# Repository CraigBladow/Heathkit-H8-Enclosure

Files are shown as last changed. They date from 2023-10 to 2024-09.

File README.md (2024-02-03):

# Heathkit-H8-Enclosure
A do it yourself enclosure designed for the Heathkit H8 Computer

Status: This is currently an incomplete work in progress.

Important: Review the license for this project before utilizing any of designs or information provided.

H8 Case Assembly 2024-02-03 15-32-41

Above: View of assembled partial case.  Below: Exploded view of assembly of the left side panel.

LeftPanelAssembly

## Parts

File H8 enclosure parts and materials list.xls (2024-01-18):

Part Name | Item | Quantity | Design Status | Source
Base plate | Baltic Birch Plywood 9mm 15” x TBD | 1 | tentative
Side Panel/Back Panel | Filament PETG 1 Kg Color - Black | 1 | alpha
hardware:
side plane mount
 | 6-32 x ¼” screw | 6 | alpha
 | 6-32 Hex standoff/stud 3/8” | 6 | alpha
Case Assembly
 | 6-32 nut | 12 | alpha
 | #6 washer | 12 | alpha
 | 8-32 x ¾ “ Pan head machine screws | 12/8 | tentative
 | 8-32 x ¾ “ Flat head machine screws | 0/4 | tentative
 | SI IUB-632-2 Mounting Hardware ULTRASONIC INSERT, BRASS | 6 | alpha
Front PCB Mount
 | 6-32 x3/8” screw | 4 | alpha
 | 6-32 nut | 4 | alpha
Circuit Card Mounts
 | 6-32 x3/8” screw | 2-4 per card | tentative
 | 6-32 nut | 2-4 per card | tentative
Not using, but it was a cool idea!
 | E-Z LOK Knife Threaded Insert for Hard-Wood, Brass Thread Inserts 6-32 Internal Threads, 0.375" | Not Used (use deprecated by TBD alternate card bracket design)

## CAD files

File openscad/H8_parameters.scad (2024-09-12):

// Heathkit H8 Computer Enclosure - Parameters and Functions
// Copyright 2024 Craig Bladow
// Released under MIT license:
//  
//        https://github.com/CraigBladow/Heathkit-H8-Enclosure/blob/main/LICENSE
//  Notes on actual H8 case parameters:
//      Front Panel support ledge front edge is 1" from front edge of side panels
//      Lid support ledge edge recessed 0.25"
//      Front Panel, Front PCB, Circuit Cards, Side Plane front edge are all parallel to each other.
//      Case side panel: Length 17", Height 6.1", Top Edge Length 13.875-13.8", Bottom Edge Length 16.6", Height 6.1", Front edge vertex Height 0.6-0.7". Differences due to three different sources.

// Calculate Angles from case dimensions so relative profile can be maintained if case depth or height changes
SideFrontEdgeUpperAngle = atan((17-13.875)/(6.1-0.6)); // Using 13.875 and 0.6 as the angle matches the sideplane circuit card angles.
//echo(SideFrontEdgeUpperAngle = SideFrontEdgeUpperAngle);
SideFrontEdgeLowerAngle = atan((17-16.6)/(0.6));
//echo(SideFrontEdgeLowerAngle=SideFrontEdgeLowerAngle);
PanelHeightToFrontEdgeHeightRatio = (0.7/6.1);
//echo(PanelHeightToFrontEdgeHeightRatio = PanelHeightToFrontEdgeHeightRatio);

// Common Constants
left = 1.0;
right = -1.0;

//All measurements in inches converted to mm unless in mm directly.
function mm(x) = x * 25.4;  //convert inches to mm
function inch(x) = x / 25.4; // convert mm to inches


// Gap to use when splitting large parts in half or fourths
Gap = 0.15 *2.0; //mm

// Compensation for ridge produced at top layer for side panel halves
ridge_h = 3 * 0.3; //mm  3 layers at 0.3 mm layer height
ridge_w = 0.3; // mm for 0.6mm nozzle and 0.3 mm height

// Case Dimension
CaseWidth = mm(16.0);

// Front Panel PCB Dimensions
FP_PCB_Length = mm(14.75);
FP_PCB_Height = mm(5.75);
PCB_Thickness = 1.6; //mm
CardsNumberToModel = 7; // Not including rear expansion connector or Front Panel and last card.
CardPCB_Length = mm(12.0);
CardPCB_Height = mm(6.0);
CardPCB_Spacing = mm(1.0+5.0/32.0);
CardPCB_FirstOffsetFromFront = mm(5.0/8.0); //Rough
CardToSidePlaneGap = mm(3.0/16.0);

// Side Panel PCB dimensions and location of mount locations
SidePlanePCBHeight = mm(5.5);
SidePlanePCBTopEdgeLength = mm(11.125);
SidePlanePCBBottomEdgeLength = mm(14.25);
SidePlanePCBFrontEdgeLength = mm(6.52);

// Side Plane position location
SP_PCB_HorizOffset = mm(-0.25); // A big guess at the moment... :)
SP_PCB_HeightFromCaseBottom = mm(1.0/8.0); //Mk 1 estimate
SP_PCB_HeightFromLedgeRecess = mm(1.0/8.0); //Mk 1 estimate
SP_PCB_StandOffHeight = 6.5; //mm

// Side Plane mount locations
SP_MountVerticalInset = mm(7.0/16.0); // distance from upper or lower edge to center of mounting holes
SP_MountTopBackHorizInset = mm(3.0/4.0); // distance from back edge to the center of first upper mounting hole
/// New moved from fit test file
SP_MountBottomBackHorizInset = mm(3.0+9.0/16.0);
SP_MountHolesOffset = mm(4.0+5.0/8.0);
/// end moved
/// old commented out
//SP_MountBottomBackHorizInset = mm(3.0+3.0/8.0); // distance from PCB back edge to the center of the first lower mounting hole
//SP_MountHolesOffset = mm(4.0+5.0/8.0)+0.4; // distance between mounting holes, 0.4 added to make it work!
// end old
SP_MountHolesVerticalOffset = 2; //mm  Needed to clear base fillet.

//echo(SidePlanePrimeSlopeAngle = SidePlanePrimeSlopeAngle);

// Side Panel overall dimensions in inches.
PanelHeight = mm(6.7); //Last: 6.6 Old 6.25 /NCCP 6.1375
PanelCornerRadius = mm(0.125);// testing orig value 0.125
PanelOverallLength = mm(17);
PanelFrontBottomRecessHeight = PanelHeightToFrontEdgeHeightRatio * PanelHeight;
//echo (PanelFrontBottomRecessHeight = inch(PanelFrontBottomRecessHeight));
//PanelFrontBottomRecessLength = mm(0.4); // was 0.5
PanelFrontBottomRecessLength = PanelFrontBottomRecessHeight * tan(SideFrontEdgeLowerAngle);
//echo(PanelFrontBottomRecessLength = inch(PanelFrontBottomRecessLength),"inch");
PanelThickness = mm(0.5);
PanelSocketsNumber = 6;

// Calculate PanelTopLength
PanelTopLength = PanelOverallLength - tan(SideFrontEdgeUpperAngle)*(PanelHeight - PanelFrontBottomRecessHeight);
//echo(PanelTopLength = PanelTopLength/25.4 , "inches");

//Check the leading case edge angle
SideFrontEdgeSlope = (PanelOverallLength-PanelTopLength)/(PanelHeight-PanelFrontBottomRecessHeight);
CheckPrimeSlopeAngle = atan(SideFrontEdgeSlope); //(PanelOverallLength-PanelTopLength)/(PanelHeight-PanelFrontBottomRecessHeight));
//echo(CheckPrimeSlopeAngle = CheckPrimeSlopeAngle);
//echo(SideFrontEdgeSlope = SideFrontEdgeSlope);

SidePlanePrimeSlopeAngle = atan((SidePlanePCBBottomEdgeLength - SidePlanePCBTopEdgeLength)/SidePlanePCBHeight);

// Front Panel Ledge
FP_LedgeLength = mm(4.0);
FP_LedgeWidth = mm(0.125);  // was 0.08 // how far the ledge sticks out
FP_LedgeHeight = mm(0.125); 
FP_LedgeAngle = 90.0 - SidePlanePrimeSlopeAngle; 
//echo (FP_LedgeAngle = FP_LedgeAngle);
FP_LedgeRecess = mm(1.0);
FP_LedgeOffsetVertical = (PanelHeight/2) - ((FP_LedgeLength/2)*cos(SidePlanePrimeSlopeAngle)) - mm(0.5);
// Solve for the Y1 value of the point on the leading edge that is the same X distance as the center of the front panel support ledge
L_M = -1.0 * SideFrontEdgeSlope;
//echo(L_M = L_M);
L_X = PanelHeight/2;
//echo(L_X = inch(L_X) , "inches");
L_Y = PanelTopLength - PanelOverallLength/2;
//echo(L_Y = inch(L_Y) , "inches");
L_B = L_Y - (L_M * L_X);
//echo(L_B = inch(L_B) , "inches");
Y1 = (L_M * FP_LedgeOffsetVertical) + L_B;
//echo(Y1 = inch(Y1) , "inches");
//FP_LedgeOffsetHorizontal = Y1;
FP_LedgeOffsetHorizontal = Y1 - (FP_LedgeRecess * cos(SidePlanePrimeSlopeAngle));
//offset = FP_LedgeRecess * cos(SidePlanePrimeSlopeAngle);
//echo(offset = inch(offset));

//- (FP_LedgeHeight * sin(SidePlanePrimeSlopeAngle));
//FP_LedgeOffsetHorizontal = PanelOverallLength/2-FP_LedgeRecess;

// Lid support
LedgeRecess = mm(0.25); // Distance from side panel top edge to top of ledge
LedgeOffset = mm(1.875); 
LedgeWidth = mm(0.125);  // Horizontal dimension, was 0.05
LedgeHeight = mm(0.125); // Vertical height of ledge
LedgeLength = mm(10.7);

// Side Panel Base Plate and Back Panel Recess , how much the side panel extends below the bottom of the base plate
BasePlateRecess = mm(0.125);
BackPanelRecess = BasePlateRecess;

// Heat Set Inserts
Insert_6_32_hole_depth = mm(0.29) + mm(0.005);
Insert_6_32_opening_dia = mm(0.206) + mm(0.002);
Insert_6_32_bottom_dia = mm(0.185) + mm(0.002);
Insert_6_32_taper_length = mm(0.150);


T_Z = (SidePlanePCBHeight/2 - SP_MountVerticalInset) + SP_MountHolesVerticalOffset + 1; // top row Z plus correction !!last adjusted by adding the +1
B_Z = -(SidePlanePCBHeight/2 - SP_MountVerticalInset)+ SP_MountHolesVerticalOffset; // bottom row Z
TY_R = SP_MountTopBackHorizInset + SP_PCB_HorizOffset; //top rear Y
TY_M = TY_R + SP_MountHolesOffset; //top middle Y
TY_F = TY_M + SP_MountHolesOffset; //top front Y
BY_R = SP_MountBottomBackHorizInset - 11.08; //bottom rear Y plus correction !!last adjusted by subtracting -1.08 which moves bottom holes towards back of case
echo(BY_R = BY_R);
BY_M = BY_R + SP_MountHolesOffset; //bottom middle Y
BY_F = BY_M + SP_MountHolesOffset; //bottom front Y

// Front Panel mount side panel insert locations relative to FP PCB bracket
FP_Mount_Offset = mm(0.5); 
// todo delete commented code
//color("lime")translate([PanelHeight/2-LedgeHeight/2-LedgeRecess,-LedgeOffset,side*(PanelThickness/2+LedgeWidth/2)])rotate([0,0,0]) Ledge(LedgeLength,LedgeWidth,LedgeHeight/2);
//FP_Z = T_Z + 12; //Front panel inset Z
//FP_X = PanelHeight/2-LedgeHeight/2-LedgeRecess - Insert_6_32_opening_dia/2;
//FP_YORIG = TY_F + 50;
//P_Y = FP_LedgeOffsetHorizontal - Insert_6_32_opening_dia;
//echo(FP_YORIG = FP_YORIG);
//echo(FP_X = FP_X);
//echo(FP_Y = FP_Y);

SP_MountLocations = [[0,TY_R,T_Z],[0,TY_M,T_Z],[0,TY_F,T_Z],[0,BY_R,B_Z],[0,BY_M,B_Z],[0,BY_F,B_Z]]; // [ Y, Z],..

//echo(MountsNew= SP_MountLocations);


/* before vertical offset 
ECHO: MountsOld = [[0, 19.05, 58.7375], [0, 136.925, 58.7375], [0, 254.8, 58.7375], [0, 85.725, -58.7375], [0, 203.6, -58.7375], [0, 321.475, -58.7375]]

after vertical 2 mm offset
ECHO: MountsNew = [[0, 19.05, 60.7375], [0, 136.925, 60.7375], [0, 254.8, 60.7375], [0, 85.725, -56.7375], [0, 203.6, -56.7375], [0, 321.475, -56.7375]]
*/

// Base Plate dimensions
BasePlateWidth = CaseWidth - 2 * PanelThickness;
BasePlateLength = mm(15); //Not verified
BasePlateHeight = 9.0; //mm Baltic Birch Plywood
BasePlateOffset = -(PanelOverallLength-BasePlateLength)/2+BackPanelRecess; 

// Back Support Dimensions, 2 instances are needed
BackSupportThickness = BasePlateHeight;
BackSupportHeight = mm(1.0);

// Fasteners
Screw_Hole_Tol = 0.1; // mm
Screw_6_32x1_4_dia = mm(0.138) + Screw_Hole_Tol;
Screw_6_32x1_4_len = mm(0.25) + Screw_Hole_Tol;
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

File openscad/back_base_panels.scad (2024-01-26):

// Heathkit H8 Computer Enclosure - Back and Base panel modules
// Copyright 2024 Craig Bladow
// Released under MIT license:
//          https://github.com/CraigBladow/Heathkit-H8-Enclosure/blob/main/LICENSE

include <H8_parameters.scad>
include <side_panels.scad>

module BasePlateBoltHoleSet(BPB_Offset)
{
    BoltClearanceX_Offset = BoltLength3_4/2-WasherRecessHeightNo8;
    BoltClearanceY_Offset1 = -WasherRecessDiameterTopNo8+BackSupportThickness/2-BasePlateMountingRailsOffset;
    BoltClearanceY_Offset2 = WasherRecessDiameterTopNo8+BackSupportThickness/2-BasePlateMountingRailsOffset;  
    BoltClearanceY_Offset3 = BasePlateLength/2-WasherRecessDiameterTopNo8;
    BoltClearanceY_Offset4 = -BasePlateLength/2 + WasherRecessDiameterTopNo8 + BackSupportThickness;
    
    color("Magenta")translate([BoltClearanceX_Offset,BoltClearanceY_Offset1,BPB_Offset])rotate([0,90,0])BoltWasherHoleNo8();
    color("Magenta")translate([BoltClearanceX_Offset,BoltClearanceY_Offset2,BPB_Offset])rotate([0,90,0])BoltWasherHoleNo8();
    color("Magenta")translate([BoltClearanceX_Offset,BoltClearanceY_Offset3,BPB_Offset])rotate([0,90,0])BoltWasherHoleNo8();
    color("Magenta")translate([BoltClearanceX_Offset,BoltClearanceY_Offset4,BPB_Offset])rotate([0,90,0])BoltWasherHoleNo8();  

}

module BasePlateBoltHoles()
{
    BoltClearanceZ_Offset = BasePlateWidth/2-BaseMountLength/2;
    BasePlateBoltHoleSet(BoltClearanceZ_Offset);
    BasePlateBoltHoleSet(-BoltClearanceZ_Offset);   
}     

module BasePlate()
{
    union()
    {
        difference()
        {
        cube([BasePlateWidth,BasePlateLength,BasePlateHeight],center=true);
        color("lime")rotate([0,90,0])BasePlateBoltHoles();
        }
        BaseFeet();
        
    }
}
module LeftBackSupport()
{
    difference()
    {
        BackSupport();
        translate([BasePlateWidth/4,0,0])cube([BasePlateWidth/2,BackSupportThickness,BackPanelHeight],center=true);
                color("lime")translate([-BasePlateWidth/4-SidePinLength/4,0,0])cube([BasePlateWidth/2-SidePinLength/2,BackSupportThickness,BackPanelHeight/1.5],center=true);
    }
            
}
module RightBackSupport()
{
    mirror([1,0,0]) LeftBackSupport();      
}

module BackSupport()
{

    difference()
    {
        cube([BasePlateWidth,BackSupportThickness,BackPanelHeight],center=true); 
        translate([BasePlateWidth/2-BackPanelBoltInset,0,0])rotate([90,90,0])BackPanelBoltHoles();
        translate([-BasePlateWidth/2+BackPanelBoltInset,0,0])rotate([90,90,0])BackPanelBoltHoles();
        
        rotate([90,90,0])SidePinPlugSockets(BackPanelHeight);
        
    }   
}
//aseFootTopDiameter = mm(0.75);
//BaseFootBottomDiameter = mm(0.5);
//BaseFootHeight = mm(0.5);
module BaseFoot()
{
    cylinder(h = BaseFootHeight, r1 = BaseFootBottomDiameter/2,r2 = BaseFootTopDiameter/2,  center = true);
}

module BaseFeet()
{
    BaseFootOffsetX = BasePlateWidth/2 - BaseMountLength - BaseFootTopDiameter;
    BaseFootOffsetY = BasePlateLength/2 - BaseFootTopDiameter;
    BaseFootOffsetZ = -BasePlateHeight/2-BaseFootHeight/2;
    translate([BaseFootOffsetX,BaseFootOffsetY,BaseFootOffsetZ])BaseFoot();
    translate([-BaseFootOffsetX,BaseFootOffsetY,BaseFootOffsetZ])BaseFoot();
    translate([BaseFootOffsetX,-BaseFootOffsetY,BaseFootOffsetZ])BaseFoot();
    translate([-BaseFootOffsetX,-BaseFootOffsetY,BaseFootOffsetZ])BaseFoot();

    
    BoltClearanceY_Offset1 = -WasherRecessDiameterTopNo8+BackSupportThickness/2-BasePlateMountingRailsOffset;
    BoltClearanceY_Offset2 = WasherRecessDiameterTopNo8+BackSupportThickness/2-BasePlateMountingRailsOffset;  
    
    BaseFootOffsetX1 = BaseFootTopDiameter;
    BaseFootOffsetYY = -BasePlateMountingRailsOffset+BackSupportThickness/2;
    BaseFootOffsetY1 = BaseFootOffsetYY+BaseFootTopDiameter;
    BaseFootOffsetY2 = BaseFootOffsetYY-BaseFootTopDiameter;
    BaseFootOffsetY3 = BaseFootOffsetYY-BaseFootTopDiameter;
    BaseFootOffsetY4 = BaseFootOffsetYY+BaseFootTopDiameter;
    translate([BaseFootOffsetX1,BaseFootOffsetY1,BaseFootOffsetZ])BaseFoot();
    translate([-BaseFootOffsetX1,BaseFootOffsetY2,BaseFootOffsetZ])BaseFoot();
    translate([BaseFootOffsetX1,BaseFootOffsetY3,BaseFootOffsetZ])BaseFoot();
    translate([-BaseFootOffsetX1,BaseFootOffsetY4,BaseFootOffsetZ])BaseFoot();
}



//$fn=128;
//BackSupport();
//LeftBackSupport();
//RightBackSupport();
//BasePlate();
//color("magenta") BaseFoot();

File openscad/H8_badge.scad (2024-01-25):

// Heathkit H8 Computer Enclosure - H8 Badge
// Copyright 2024 Craig Bladow
// Released under MIT license:
// Uses hilbert texture per:
// https://github.com/prusa3d/PrusaSlicer/issues/4455
// Status is testing, font and style and dimensions are TBD


letter_height = 0.2001; //Match layer height

module letter(letter,letter_height, size)
{

    // convexity is needed for correct preview
    // since characters can be highly concave
    linear_extrude(height=letter_height, convexity=4)
        text(letter, 
             size=size,//width*22/30,
             //font="Bitstream Vera Sans:style=Bold",
             //font="Liberation Sans:style=Bold",
             //font="Liberation Sans",
             //font="Liberation Sans:style=Italic",
            //font="DM Sans Medium:style=Bold",
            //font="DM Sans Medium:style=Italic",
            font="Rodeo58",
            //font="DM Sans Medium:",
             halign="center",
             valign="center");
}

module letter_font(letter,lfont, letter_height, size)
{

    // convexity is needed for correct preview
    // since characters can be highly concave
    linear_extrude(height=letter_height, convexity=4)
        text(letter, 
             size=size,//width*22/30,
            font=lfont,
             halign="center",
             valign="center");
}

module heathkit(name,calc,hhc,location)
{
        rotate([0,180,90]) letter("HEATHKIT",letter_height,10);
}



heathkit();
/*
difference()
{
    cube([20,20,4],center = true);
    translate([0,0,2])cube([16,16,4],center = true);
} */

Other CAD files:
openscad/H8_back_base_panels.scad
H8_fit_test_pieces.scad
openscad/H8_Case.scad
openscad/H8_PCB_Assembly.scad
openscad/H8_card_brackets.scad
openscad/H8_fit_test_pieces.scad
openscad/H8_side_panels.scad
openscad/fit_test_pieces.scad

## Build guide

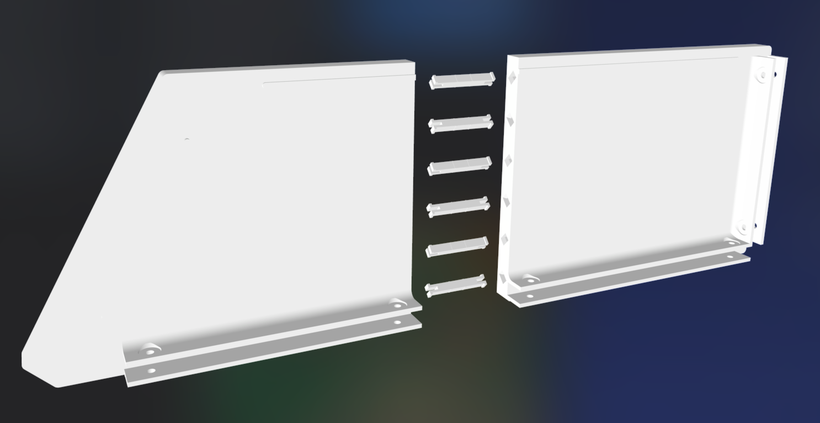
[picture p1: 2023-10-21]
Assembly Diagrams/LeftPanelAssembly.png

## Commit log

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2023-09-05 Updated side panel parameters and created H8 case and parameter scad files.
    [H8_Case.scad, H8_parameters.scad, side_panels.scad]
2023-09-05 Overall assembly tweak pplus base plate best guess.
    [H8_Case.scad, H8_parameters.scad]
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2023-09-08 Updated dimensions and support ledges added to side panels.
    [H8_Case.scad, H8_parameters.scad, side_panels.scad]
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2023-09-09 Initial commit enclosure parts and materials list spreadsheet.
    [H8 enclosure parts and materials list.xls]
2023-09-09 Case right side panel and base plate updates.
    [H8 enclosure parts and materials list.xls, H8_Case.scad, H8_parameters.scad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]
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2023-09-15 Added side panel initial pin definition for testing.
    [H8_parameters.scad, side_panels.scad]
2023-09-16 Socket and pin test tolerance commit.
    [H8_parameters.scad, side_panels.scad]
2023-09-16 Initial snap pin development.
    [H8_parameters.scad, side_panels.scad]
2023-09-16 Snap pin development update.
    [H8_parameters.scad, side_panels.scad]
2023-09-17 Snap connectin pin and socket development.
    [H8_parameters.scad, side_panels.scad]
2023-09-17 Snap connection pin testing addition of a small bump to reduce wiggle.
    [side_panels.scad]
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2023-09-18 Front half of left panel development in progress.
    [H8_parameters.scad, side_panels.scad]
2023-09-18 Fixed lid support ledge not connected to side panel.
    [side_panels.scad]
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2023-09-24 Added bottom mount to test side panel slice.
    [card_brackets.scad, side_panels.scad]
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2023-09-29 Modified sockets for pins in side panel. Updated H8_Case.scad.
    [H8_Case.scad]
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2023-09-29 Created PanelMount module to generate panel mounting rails.
    [side_panels.scad]
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2023-10-02 Work in progress on back panel mounts. Fillet trimmed.
    [side_panels.scad]
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2023-10-13 Working on aligning base plate mounting rails with base plate in side_panels.scad module LeftPanel. Not complete.
    [H8_Case.scad, H8_parameters.scad, side_panels.scad]
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2023-10-16 Calculate Front Panel supports slope angle from side panel parameters.
    [H8_Case.scad, H8_parameters.scad]
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2023-10-20 Shortened base plate and fixed bolt hole locations in base mount rail.
    [H8_Case.scad, H8_parameters.scad, side_panels.scad]
2023-10-21 Created LeftPanelExplodedAssembly() to show how left panel goes together. Added LeftPanelAssembly diagram.
    [H8_Case.scad]
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2023-10-21 Added fit_test.scad to generate pieces for fit up testing only.
    [fit_test_pieces.scad]
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2023-10-25 Added printing notes to H8_case.scad and initial non-snapping pins for fit testing.
    [H8_Case.scad, fit_test_pieces.scad]
2023-10-26 Right side panel updated to be the mirror of the left panel.
    [H8_Case.scad, fit_test_pieces.scad, side_panels.scad]
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2023-10-31 Base plate model feet added and initial rear left section in progress.
    [H8_Case.scad, H8_parameters.scad, back_base_panels.scad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]
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2023-11-02 Increased cutout height forbase plate front pieces to remove overhang in foot structure.
    [fit_test_pieces.scad]
2024-01-11 Preliminary work on side plane mount to case.
    [H8_Case.scad, H8_PCB_Assembly.scad, H8_parameters.scad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]
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2024-01-26 Testing lower profile flathead screws for case assembly.
    [H8_Case.scad, H8_parameters.scad, card_brackets.scad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]
2024-01-26 Further testing of lower profile flathead screws for case assembly.
    [H8_Case.scad, side_panels.scad]
2024-01-26 Further testing of lower profile flathead screws for case assembly.Created TestBaseChunk.
    [back_base_panels.scad, side_panels.scad]
2024-01-27 Further testing of lower profile flathead screws for case assembly. Using TestBaseChunk.
    [fit_test_pieces.scad, side_panels.scad]
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2024-01-29 Adjusted FP support ledge angle and case side leading angles to match. Awaiting confirmation of actual angle.
    [H8_Case.scad, H8_parameters.scad, side_panels.scad]
2024-01-30 Calculate length of case side based on overall length to match original case slope.
    [H8_Case.scad, H8_parameters.scad]
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2024-02-02 Increased PanelHeight to 6.6 inches from 6.25 inches.
    [H8_parameters.scad]
2024-02-02 Check in prior to adjusting front panel support ledge.
    [H8_Case.scad, H8_parameters.scad]
2024-02-02 In progress locating frontpanell support ledge and case sides undercuts.
    [H8_Case.scad, H8_parameters.scad, side_panels.scad]
2024-02-03 Front Panel Ledge offset from front edge. In progress.
    [H8_parameters.scad, side_panels.scad]
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2024-02-03 Front Panel calculated offset implemented. Revised Panel() to use offset() instead of hull().
    [H8_Case.scad, H8_parameters.scad, side_panels.scad]
2024-02-03 Added model of circuit cards and side plane to overall H8 model.
    [H8_Case.scad, H8_PCB_Assembly.scad, H8_parameters.scad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]
2024-02-03 Added circuit boards and powers supply to case overview model.
    [H8_Case.scad, H8_parameters.scad]
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2024-02-05 Working on location of sideplane insert locations. See SidePlaneMountingInsets().
    [H8_Case.scad, H8_PCB_Assembly.scad, H8_parameters.scad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]
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2024-02-08 Reduced cut outs for fit test side panels.
    [H8_Case.scad, fit_test_pieces.scad]
2024-02-08 Renamed .scad files to all have H8 prefix.
    [H8_badge.scad, H8_card_brackets.scad, H8_side_panels.scad]
2024-02-08 Insert locations for side plane finalized for fit test.
    [H8_side_panels.scad]
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2024-02-09 Created small gap between halves of the side panels to faciliate assembly.
    [H8_Case.scad, H8_fit_test_pieces.scad, H8_parameters.scad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]
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2024-05-20 extended height of case to 6.7 inches from 6.6 inches, 2.54 mm, to accomodate shifting sideplane PCB upwards by 2 mm.
    [H8_parameters.scad]
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2024-05-28 Upper Front Panel attach insert location rough guess. Need to calculate based on Front Panel support ledge parameters.
    [H8_Case.scad, H8_parameters.scad]
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2024-08-19 Corrected direction of previous adjustment.
    [H8_fit_test_pieces.scad, H8_parameters.scad]
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2024-09-12 fixed PCB mount point regression
    [H8_Case.scad, H8_fit_test_pieces.scad, H8_parameters.scad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]
